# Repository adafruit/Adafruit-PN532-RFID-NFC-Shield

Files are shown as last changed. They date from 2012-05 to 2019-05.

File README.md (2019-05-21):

## Adafruit PN532 RFID/NFC Shield for Arduino
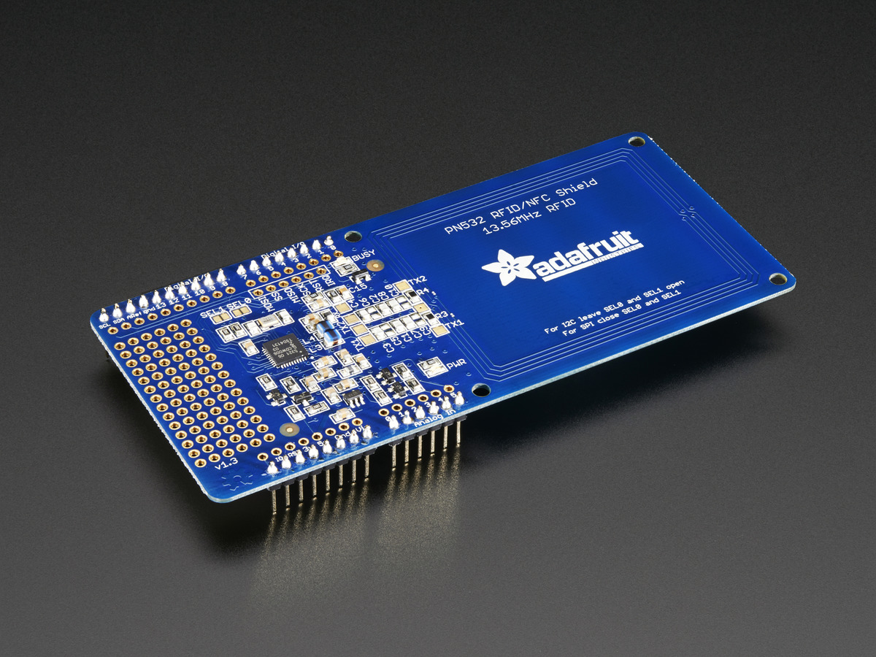
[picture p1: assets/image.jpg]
<a href="http://www.adafruit.com/products/789"><br/>
Click here to purchase one from the Adafruit shop</a>

We've taken our popular Adafruit PN532 breakout board and turned it into a shield - the perfect tool for any 13.56MHz RFID or NFC application. The Adafruit NFC shield uses the PN532 chip-set (the most popular NFC chip on the market) and is what is embedded in pretty much every phone or device that does NFC. It can pretty much do it all, such as read and write to tags and cards, communicate with phones (say for payment processing), and 'act' like a NFC tag. If you want to do any sort of embedded NFC work, this is the chip you'll want to use! 

These are the Eagle CAD files for the Adafruit PN532 RFID/NFC Shield for Arduino:
- http://www.adafruit.com/products/789

### License

Adafruit invests time and resources providing this open source design, please support Adafruit and open-source hardware by purchasing products from [Adafruit](https://www.adafruit.com)!

All text above must be included in any redistribution

Designed by Limor Fried/Ladyada and Kevin Townsend for Adafruit Industries.
Creative Commons Attribution/Share-Alike, all text above must be included in any redistribution. 
See license.txt for additional information.

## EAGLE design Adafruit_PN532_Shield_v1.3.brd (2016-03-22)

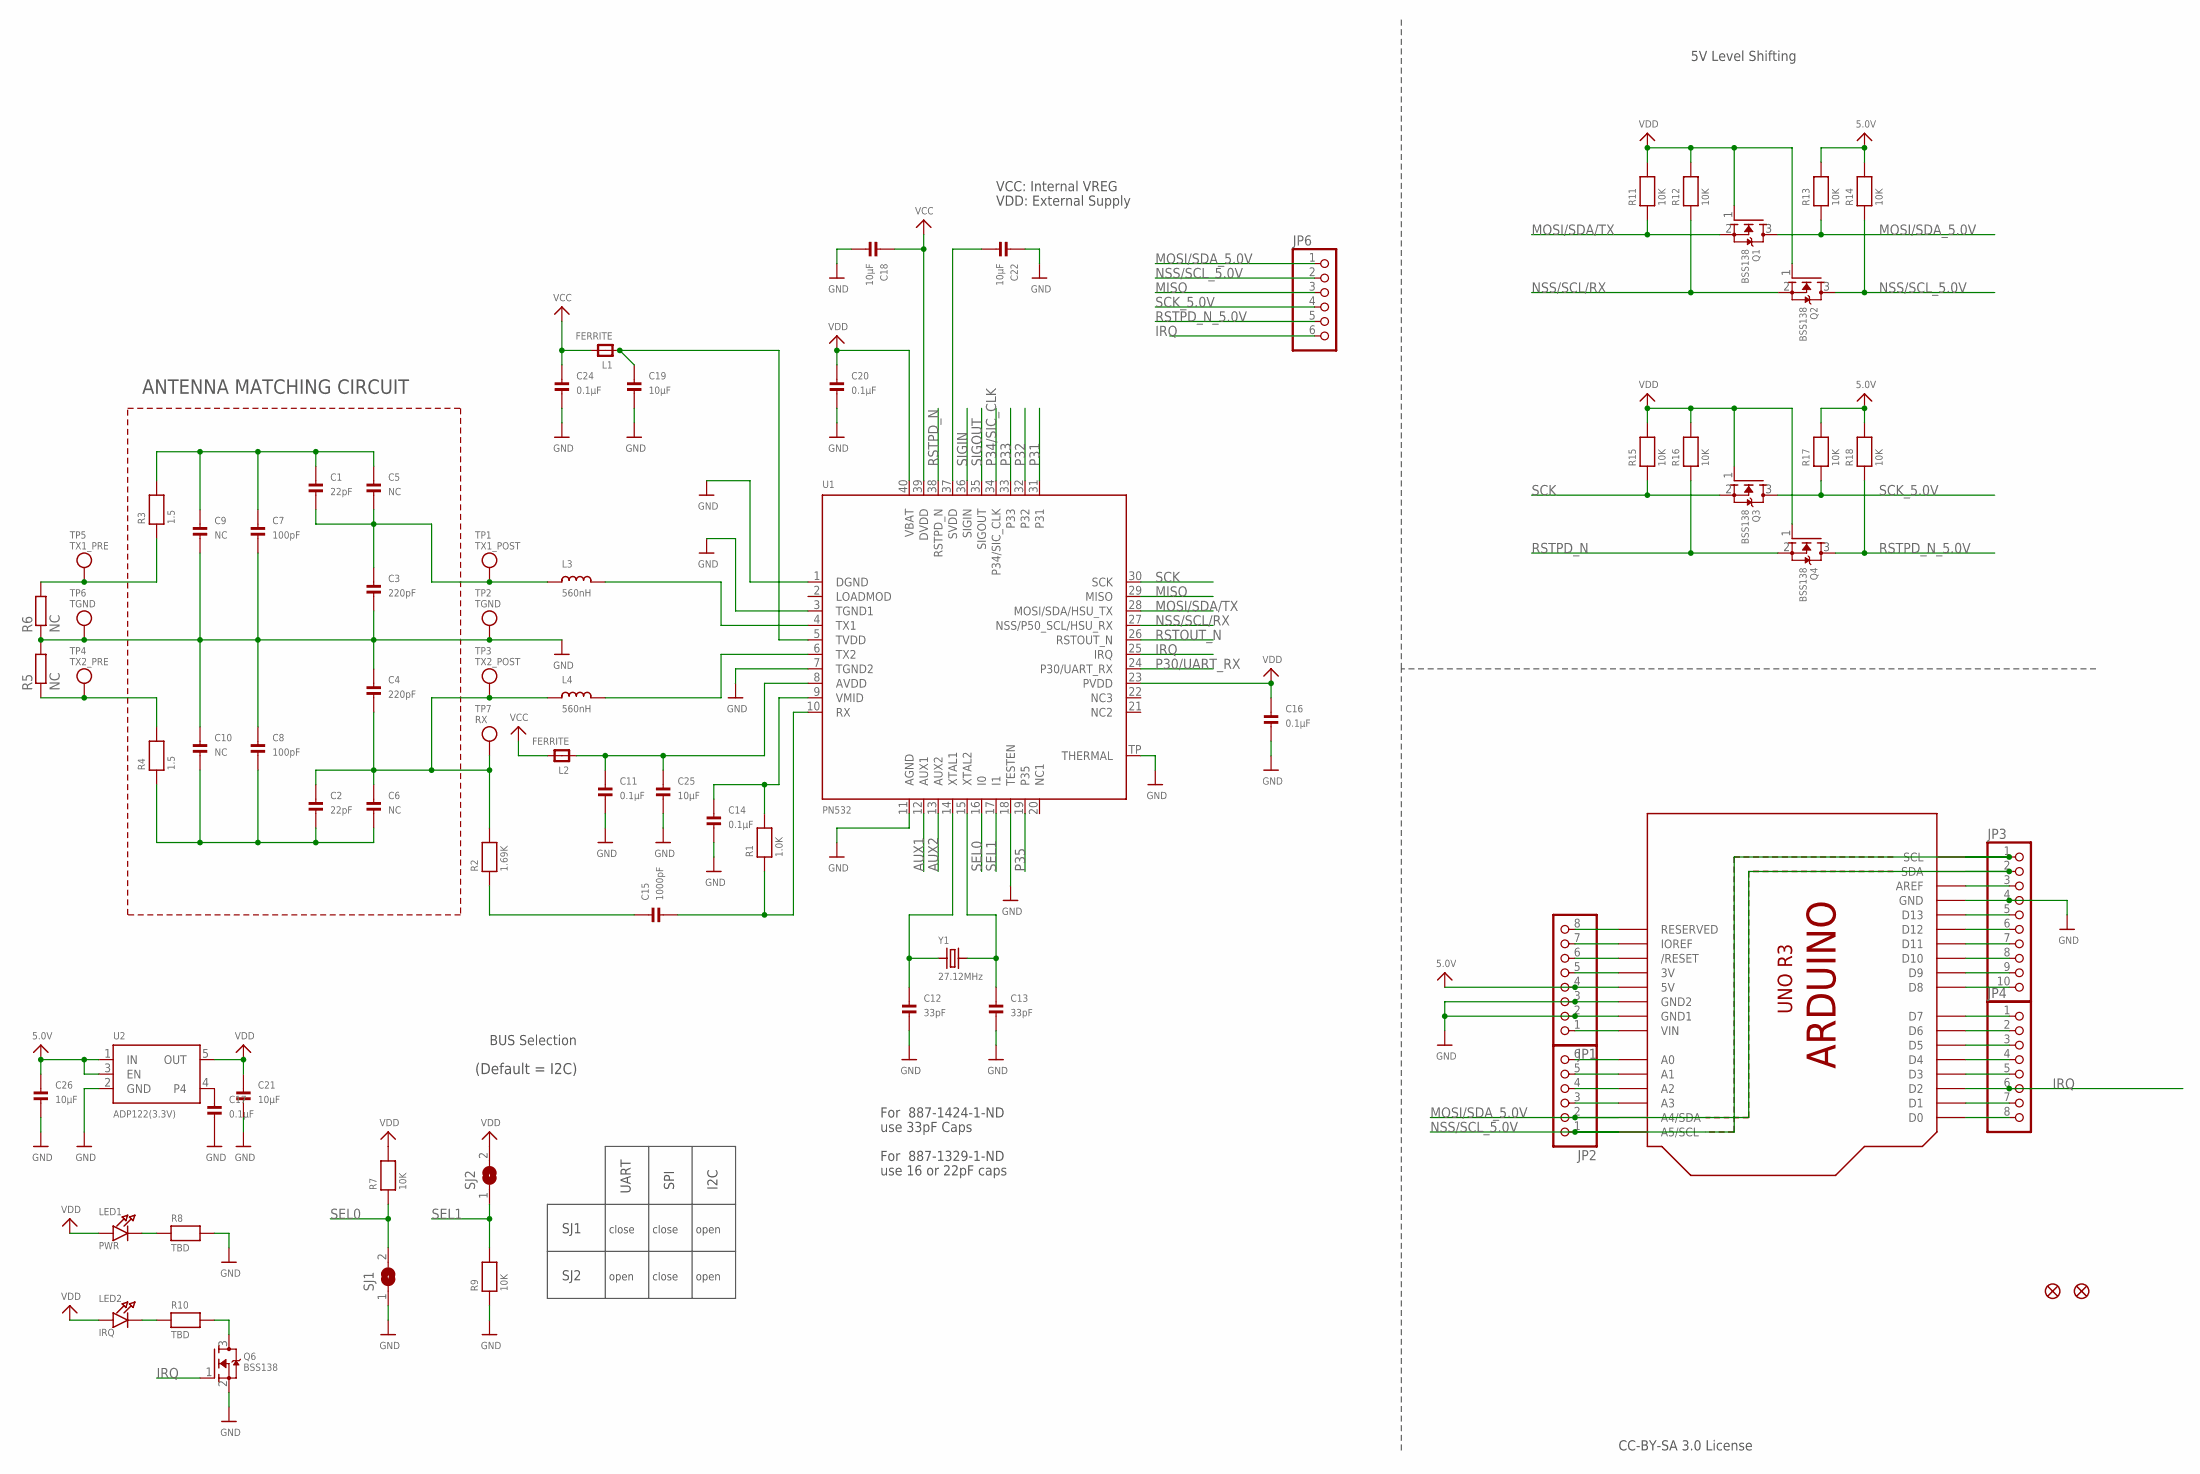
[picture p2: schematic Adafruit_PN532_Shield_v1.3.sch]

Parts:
C1, C2: 22pF; 0805
C3, C4: 220pF; 0805
C5, C6, C9, C10: NC; 0805
C7, C8: 100pF; 0805
C11, C14, C16, C17, C20, C24: 0.1µF; 0805
C12, C13: 33pF; 0805
C15: 1000pF; 0805
C18, C19, C21, C22, C25, C26: 10µF; 0805
FID1, FID2: FIDUCIAL1X2.5; FIDUCIAL-1X2.5
JP1, JP4: HEADER-1X870MIL; 1X08_ROUND_70
JP2: HEADER-1X670MIL; 1X06_ROUND_70
JP3: HEADER-1X1070MIL; 1X10_ROUND70
JP6: PINHD-1X6B; 1X06-BIG
L1, L2: FERRITE; 0805
L3, L4: 560nH; 0805
LED1: PWR; CHIPLED_0805
LED2: IRQ; CHIPLED_0805
Q1, Q2, Q3, Q4, Q6: BSS138; SOT23-WIDE
R1: 1.0K; 0805
R2: 1.69K; 0805
R3, R4: 1.5; 0805
R5, R6: NC; R0201
R7, R9, R11, R12, R13, R14, R15, R16, R17, R18: 10K; 0805
R8, R10: TBD; 0805
SJ1, SJ2: SOLDERJUMPERREFLOW_NOPASTE; SOLDERJUMPER_REFLOW_NOPASTE
TP1: TX1_POST; TESTPOINT_PAD_2MM
TP2, TP6: TGND; TESTPOINT_PAD_2MM
TP3: TX2_POST; TESTPOINT_PAD_2MM
TP4: TX2_PRE; TESTPOINT_PAD_2MM
TP5: TX1_PRE; TESTPOINT_PAD_2MM
TP7: RX; TESTPOINT_PAD_2MM
U1: PN532; HVQFN40-6X6
U2: ADP122(3.3V); SOT23-5
U3: ARDUINOR3NODIM; ARDUINOR3-NODIM
Y1: 27.12MHz; CRYSTAL_3.2X2.5

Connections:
5.0V: C26.1, JP1.4, R13.2, R14.2, R17.2, R18.2, U2.1 (IN), U2.3 (EN), U3.5V
AUX1: U1.12 (AUX1)
AUX2: U1.13 (AUX2)
GND: C3.2, C4.1, C7.2, C8.1, C9.2, C10.1, C11.2, C12.2, C13.2, C14.2, C16.2, C17.2, C18.2, C19.2, C20.2, C21.2, C22.1, C24.2, C25.2, C26.2, JP1.2, JP1.3, JP3.4, Q6.2 (S), R5.2, R6.1, R8.2, R9.1, SJ1.1, TP2.P$1, TP6.P$1, U1.1 (DGND), U1.3 (TGND1), U1.7 (TGND2), U1.11 (AGND), U1.18 (TESTEN), U1.TP (THERMAL), U2.2 (GND), U3.GND, U3.GND1, U3.GND2
IRQ: JP4.6, JP6.6, Q6.1 (G), U1.25 (IRQ), U3.D2
MISO: JP6.3, U1.29 (MISO)
MOSI/SDA/TX: Q1.2 (S), R11.1, U1.28 (MOSI/SDA/HSU_TX)
MOSI/SDA_5.0V: JP2.2, JP3.2, JP6.1, Q1.3 (D), R13.1, U3.A4 (A4/SDA), U3.SDA
unnamed: L3.2, U1.4 (TX1)
unnamed: L4.2, U1.6 (TX2)
unnamed: C1.2, C3.1, C5.2, L3.1, TP1.P$1
unnamed: R3.1, R6.2, TP5.P$1
unnamed: R4.2, R5.1, TP4.P$1
unnamed: LED1.C, R8.1
unnamed: C12.1, U1.14 (XTAL1), Y1.1
unnamed: C13.1, U1.15 (XTAL2), Y1.2
unnamed: C15.1, R2.1
unnamed: C14.1, R1.2, U1.9 (VMID)
unnamed: C15.2, R1.1, U1.10 (RX)
unnamed: C2.1, C4.2, C6.1, L4.1, R2.2, TP3.P$1, TP7.P$1
unnamed: C11.1, C25.1, L2.1, U1.8 (AVDD)
unnamed: C19.1, L1.1, U1.5 (TVDD)
unnamed: JP1.1, U3.VIN
unnamed: JP1.5, U3.3V
unnamed: JP1.6, U3.RESET (/RESET)
unnamed: JP1.7, U3.IOREF
unnamed: JP1.8, U3.RESERVED
unnamed: JP2.3, U3.A3
unnamed: JP2.4, U3.A2
unnamed: JP2.5, U3.A1
unnamed: JP2.6, U3.A0
unnamed: JP3.3, U3.AREF
unnamed: JP3.5, U3.D13
unnamed: JP3.6, U3.D12
unnamed: JP3.7, U3.D11
unnamed: JP3.8, U3.D10
unnamed: JP3.9, U3.D9
unnamed: JP3.10, U3.D8
unnamed: JP4.1, U3.D7
unnamed: JP4.2, U3.D6
unnamed: JP4.3, U3.D5
unnamed: JP4.4, U3.D4
unnamed: JP4.5, U3.D3
unnamed: LED2.C, R10.1
unnamed: JP4.7, U3.D1
unnamed: JP4.8, U3.D0
unnamed: Q6.3 (D), R10.2
unnamed: C17.1, U2.4
unnamed: C22.2, U1.37 (SVDD)
NSS/SCL/RX: Q2.2 (S), R12.1, U1.27 (NSS/P50_SCL/HSU_RX)
NSS/SCL_5.0V: JP2.1, JP3.1, JP6.2, Q2.3 (D), R14.1, U3.A5 (A5/SCL), U3.SCL
P30/UART_RX: U1.24 (P30/UART_RX)
P31: U1.31
P32: U1.32
P33: U1.33
P34/SIC_CLK: U1.34 (P34/SIC_CLK)
P35: U1.19 (P35)
RSTOUT_N: U1.26 (RSTOUT_N)
RSTPD_N: Q4.2 (S), R16.1, U1.38 (RSTPD_N)
RSTPD_N_5.0V: JP6.5, Q4.3 (D), R18.1
SCK: Q3.2 (S), R15.1, U1.30 (SCK)
SCK_5.0V: JP6.4, Q3.3 (D), R17.1
SEL0: R7.1, SJ1.2, U1.16 (I0)
SEL1: R9.2, SJ2.1, U1.17 (I1)
SIGIN: U1.36 (SIGIN)
SIGOUT: U1.35 (SIGOUT)
TX1_ANTENNA: C1.1, C5.1, C7.1, C9.1, R3.2
TX2_ANTENNA: C2.2, C6.2, C8.2, C10.2, R4.1
VCC: C18.1, C24.1, L1.2, L2.2, U1.39 (DVDD)
VDD: C16.1, C20.1, C21.1, LED1.A, LED2.A, Q1.1 (G), Q2.1 (G), Q3.1 (G), Q4.1 (G), R7.2, R11.2, R12.2, R15.2, R16.2, SJ2.2, U1.23 (PVDD), U1.40 (VBAT), U2.5 (OUT)

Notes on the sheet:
ANTENNA MATCHING CIRCUIT
SJ1
SJ2
UART
SPI
I2C
close
open
CC-BY-SA 3.0 License
For 887-1329-1-ND
use 16 or 22pF caps
For 887-1424-1-ND
use 33pF Caps
BUS Selection
(Default = I2C)
5V Level Shifting
VCC: Internal VREG
VDD: External Supply

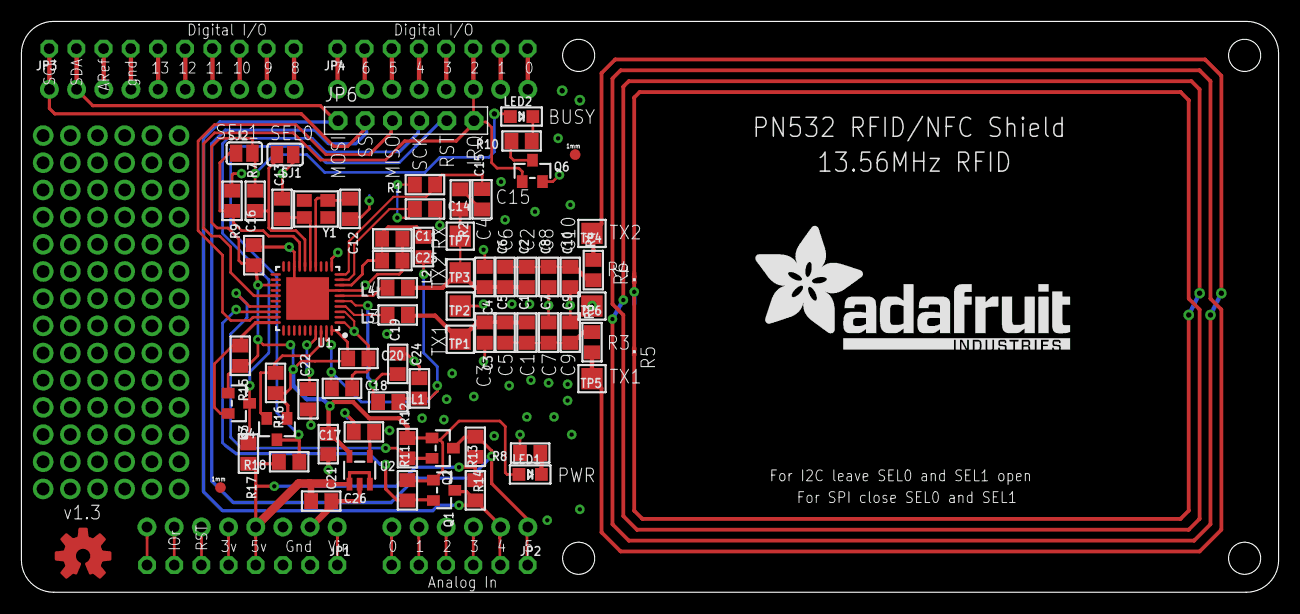
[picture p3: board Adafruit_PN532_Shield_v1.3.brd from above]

Board: 2 copper layers, 117.5 x 53.3 mm, 76 parts (0 on the bottom side), 59 nets.

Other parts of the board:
U$3: ADAFRUIT_TEXT_30MM
U$50: OSHWLOGO_TOP_0.2
